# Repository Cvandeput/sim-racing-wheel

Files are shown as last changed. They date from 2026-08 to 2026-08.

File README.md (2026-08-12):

<div align="center">

# Sim Racing Wheel

**Volant de simulation type F1, conçu de zéro : modélisation 3D, PCB custom, firmware Arduino.**

Fusion 360 · PCB 2 couches · Arduino Nano · 18 LEDs RGB · écran OLED · palettes à charnière

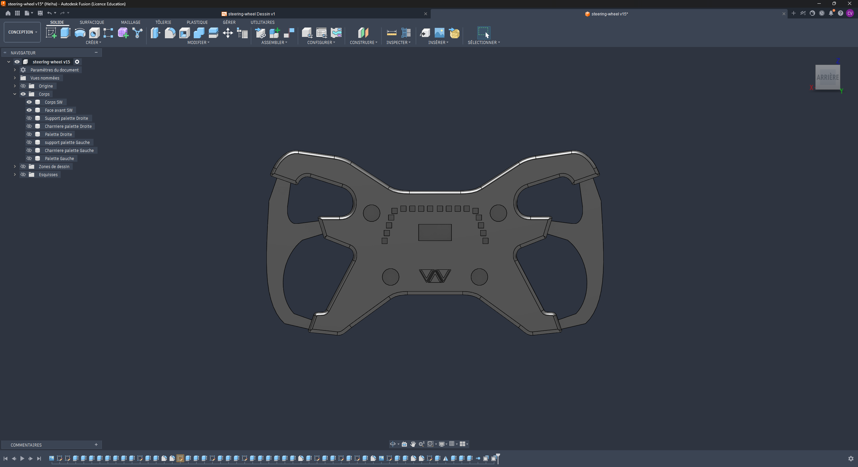
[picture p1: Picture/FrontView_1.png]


</div>

> **🚧 Work in progress** — la mécanique et l'électronique sont finalisées. Le firmware gère l'OLED, les rapports, le chronomètre et le compte-tours ; il reste à le brancher sur une vraie source de télémétrie.

---

## Description

Volant de simulation automobile inspiré des monoplaces de F1, entièrement conçu et fabriqué maison. La coque est modélisée dans Fusion 360 et imprimée en 3D, l'électronique repose sur un PCB deux couches dessiné pour l'occasion, et l'ensemble se connecte en USB-C.

Le volant intègre une barre de 18 LEDs RGB adressables faisant office de compte-tours, un écran OLED central pour la télémétrie, deux encodeurs rotatifs, des boutons poussoirs, et deux palettes de changement de vitesse montées sur charnières.

## Conception 3D

Modélisé sous Fusion 360 en corps séparés : coque principale, face avant, supports de palettes, charnières et palettes gauche/droite.

| Vue de face | Vue trois-quarts |
|:---:|:---:|
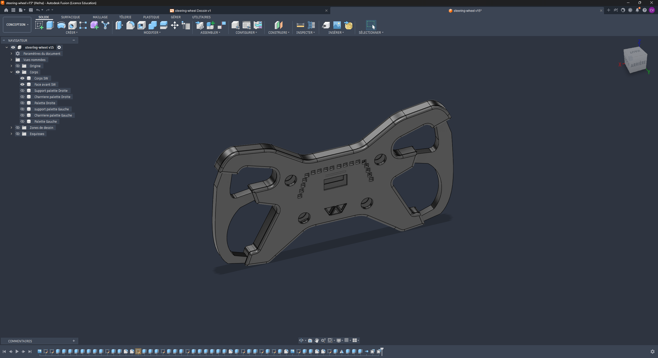
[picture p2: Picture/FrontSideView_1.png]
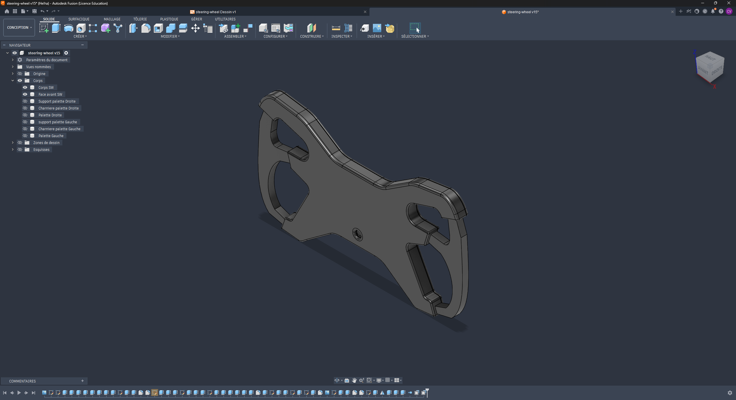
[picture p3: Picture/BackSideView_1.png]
|  |  |

**Face arrière** — nervures de rigidification, logements de vis et passages de câbles vers les palettes.

<div align="center">
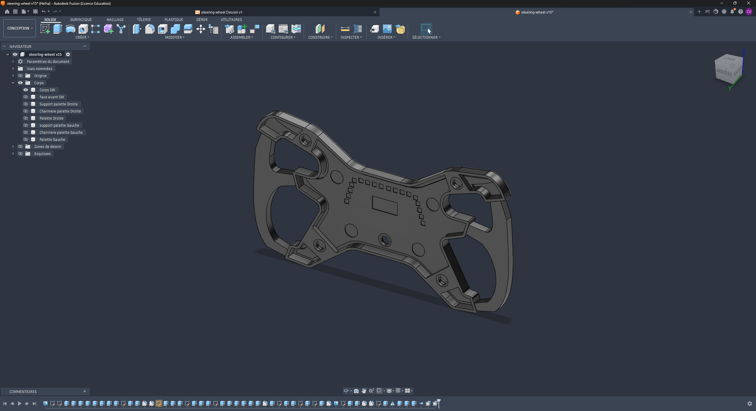
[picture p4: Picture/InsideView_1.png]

</div>

**Dessin technique coté**

<div align="center">
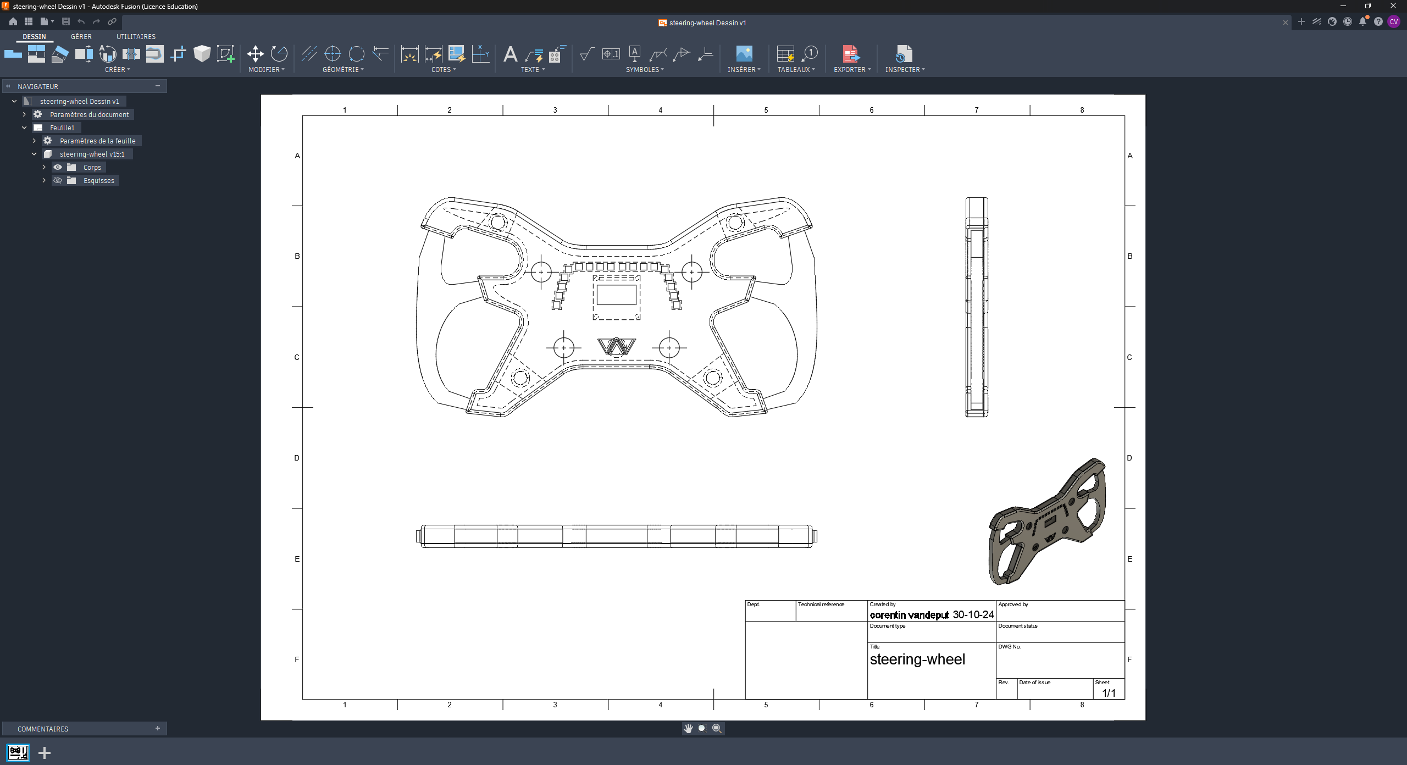
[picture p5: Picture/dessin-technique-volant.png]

</div>

---

## Électronique

PCB deux couches dessiné sous EasyEDA, fichiers Gerber et pick-and-place prêts pour la production.

| Réf. | Qté | Composant | Rôle |
|---|:---:|---|---|
| U1 | 1 | Arduino Nano | Contrôleur, interface USB HID |
| LED1-18 | 18 | WS2812B-V5/W | Barre de compte-tours RGB adressable |
| OLED1 | 1 | HS13L03W2C01 | Affichage télémétrie |
| SW1-2 | 2 | ALPS EC11E09244BS | Encodeurs rotatifs cliquables |
| SWITCH1-2 | 2 | K6-6275D03 | Boutons poussoirs |
| USBC1 | 1 | MC-311D | Connecteur USB-C |
| C1-18 | 18 | 100 nF | Découplage, un par LED |
| R1 | 1 | 470 Ω | Résistance de ligne de données WS2812B |
| R2-5 | 4 | 220 Ω | Limitation de courant |

Nomenclature complète, empreintes et références LCSC dans `PCB/BOM_Board1_PCB1_2024-10-15.xlsx`.

Le découplage à 100 nF par LED et la résistance série de 470 Ω sur la ligne de données suivent les recommandations du fabricant WS2812B — sans elles, une chaîne de 18 LEDs devient instable.

---

## Firmware

Arduino Nano, OLED SSD1306 en I2C, six boutons en `INPUT_PULLUP`, barre de LEDs adressables et potentiomètre simulant le capteur de régime. Le projet est développé et simulable sous Wokwi : [wokwi.com/projects/400891434411566081](https://wokwi.com/projects/400891434411566081).

<div align="center">
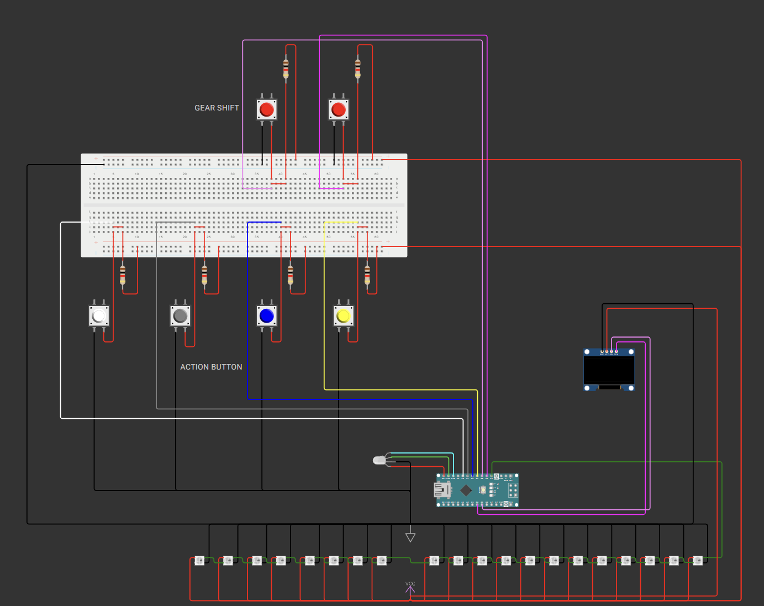
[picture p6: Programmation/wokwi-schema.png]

</div>

### Affectation des broches

| Broche | Signal | Rôle |
|:---:|---|---|
| D2 | `led` (NeoPixel) | Ligne de données de la barre WS2812B |
| D3 | `BP_DWS` | Palette gauche — rétrograder |
| D4 | `BP_UPS` | Palette droite — monter un rapport |
| D5 | `BP_GE` | Affiche le rapport engagé |
| D6 | `BP_CHR_RST` | Remise à zéro du chronomètre |
| D7 | `BP_CHR` | Chronomètre — start / pause / reprise |
| D8 | `BP_RPM` | Affiche le régime moteur |
| A3 | `potentiometre` | Capteur de régime (potentiomètre en simulation) |
| A4 / A5 | `SDA` / `SCL` | Bus I2C de l'OLED (adresse `0x3C`) |

### Fonctionnement

**Rapports** — les palettes incrémentent et décrémentent `Gear_Engaged` de N à 5. L'écran ne se rafraîchit que si le rapport a changé, via `previousGearDisplayed`, pour éviter de redessiner l'OLED à chaque tour de boucle.

**Compte-tours** — la lecture analogique 0-1023 est découpée en vingt paliers qui remplissent progressivement la barre : vert jusqu'à neuf LEDs, puis rouge, puis magenta sur les cinq dernières. C'est la logique classique d'un shift light de F1 : le pilote change de rapport quand la zone magenta s'allume.

**Chronomètre** — machine à trois états (`stop` / `run` / `pause`) avec détection de relâchement du bouton, plus un bouton de reset dédié.

**Écran** — l'affichage courant est mémorisé dans `AFF`, ce qui permet de savoir quelle vue redessiner après un changement d'état.

### Dépendances

`Adafruit GFX`, `Adafruit SSD1306` et `Adafruit NeoPixel` — voir `Programmation/libraries.txt`.

### Points à corriger

- La barre est déclarée à **21 LEDs** dans le firmware alors que le PCB en compte **18**. Les indices 16 à 20 de la zone magenta pointent hors de la chaîne physique.
- L'écran RPM affiche la chaîne littérale `"valeur-RPM"` au lieu de `pot_cap_RPM`.
- Les vingt `if` en cascade du compte-tours sont indépendants et tous évalués à chaque tour ; une boucle avec un seuil calculé ferait la même chose en cinq lignes.
- `MonEcran.setCursor(1000, 1000)` au démarrage place le texte d'initialisation hors de l'écran.
- Les `delay(200)` et `delay(1000)` bloquent la lecture des boutons pendant l'antirebond.

---

## Structure du projet

```
├── 3D/
│   ├── steering-wheel v12.stl / .3mf   # Modèle courant
│   ├── Plan steerign wheel.pdf         # Plan coté
│   └── Previous/                       # Itérations v11 à v13
├── PCB/
│   ├── Gerber_PCB1_2024-10-15.zip      # Fichiers de fabrication
│   ├── BOM_Board1_PCB1_2024-10-15.xlsx # Nomenclature
│   ├── PickAndPlace_PCB1_2024-10-15.*  # Placement composants
│   ├── PCB-steeringWheel.epro          # Projet EasyEDA
│   └── contour-volant.dxf              # Contour du PCB
├── Programmation/
│   ├── sketch.ino                      # Firmware Arduino
│   ├── diagram.json                    # Schéma de câblage Wokwi
│   ├── wokwi-schema.png                # Rendu du schéma
│   ├── libraries.txt                   # Bibliothèques requises
│   ├── logo-binaire.txt                # Bitmap du logo pour l'OLED
│   └── g1177.png                       # Source du logo
└── Picture/                            # Rendus et dessins techniques
```

## Fabrication

**Impression 3D** — imprimer `3D/steering-wheel v12.3mf`. PLA ou PETG, couches de 0.2 mm, remplissage 25 % minimum sur la coque qui encaisse les efforts de direction, supports nécessaires sur les logements de palettes.

**PCB** — envoyer `PCB/Gerber_PCB1_2024-10-15.zip` à un fabricant (JLCPCB, PCBWay). Pour l'assemblage automatisé, joindre le BOM et le fichier pick-and-place, les références LCSC y sont déjà renseignées.

**Firmware** — ouvrir `Programmation/sketch.ino` dans l'IDE Arduino, ou importer `diagram.json` et `sketch.ino` sur Wokwi pour simuler sans matériel.

## Reste à faire

- [x] Publier le firmware Arduino et le schéma Wokwi
- [x] Documenter le mapping des broches
- [x] Piloter la barre WS2812B (compte-tours)
- [ ] Aligner le nombre de LEDs du firmware (21) sur celui du PCB (18)
- [ ] Afficher la vraie valeur de régime sur l'OLED
- [ ] Remplacer la cascade de vingt `if` par une boucle
- [ ] Remplacer les `delay()` par un antirebond non bloquant
- [ ] Remplacer le potentiomètre par une vraie source de télémétrie
- [ ] Photos du volant assemblé
- [ ] Câblage des palettes et choix des switches
- [ ] Support de fixation sur base de force feedback

---

<div align="center">

**Vandeput Corentin** · [devworks.be](https://devworks.be)

</div>

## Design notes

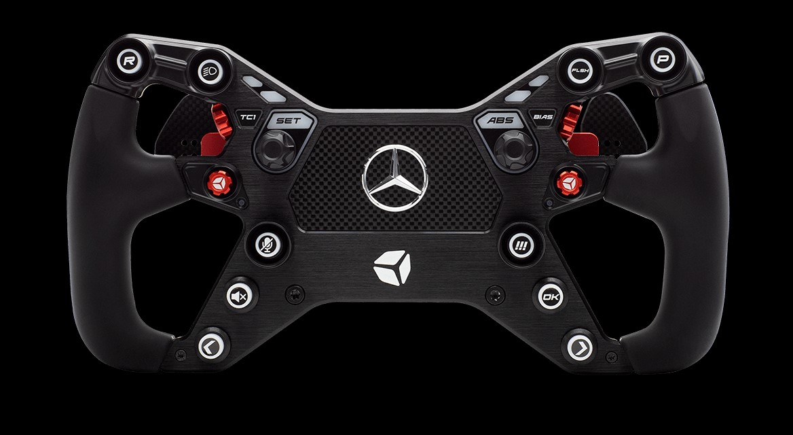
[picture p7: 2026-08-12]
Picture/Capture d’écran 2024-07-02 215142.jpg

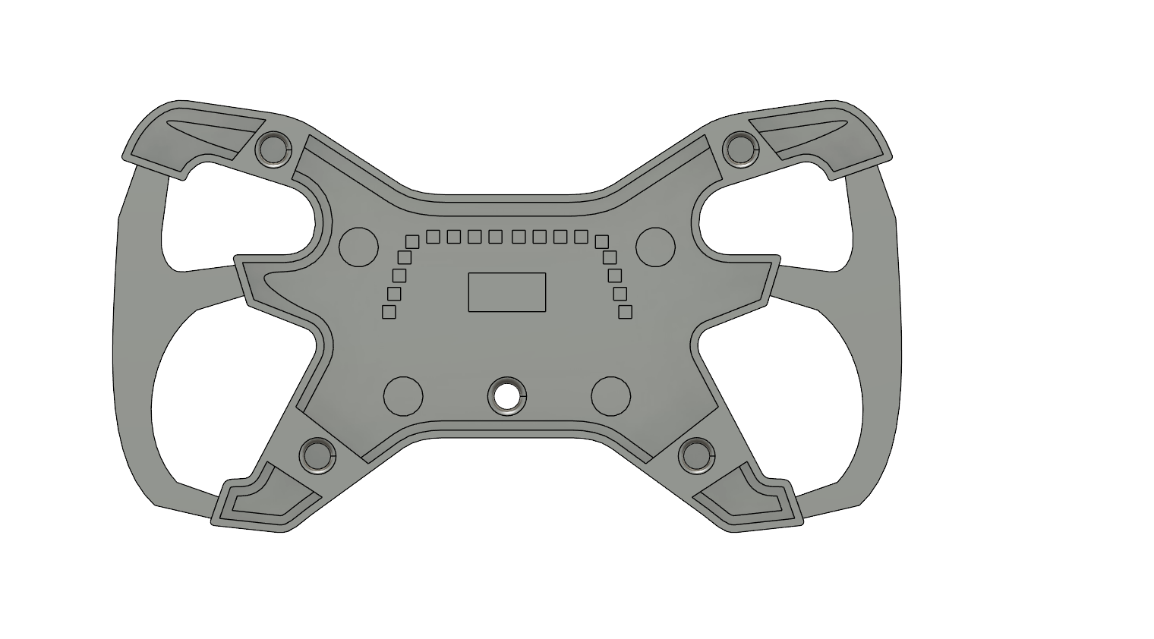
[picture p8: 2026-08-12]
Picture/steering-wheel v10.png

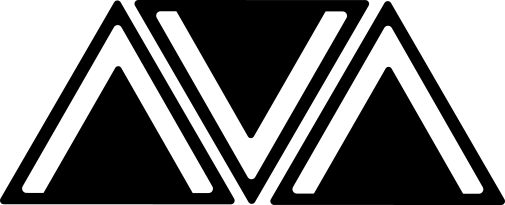
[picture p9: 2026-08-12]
Programmation/g1177.png

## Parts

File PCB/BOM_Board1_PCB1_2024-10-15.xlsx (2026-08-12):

No. | Quantity | Comment | Designator | Footprint | Value | Manufacturer Part | Manufacturer | Supplier Part | Supplier
1 | 18 | 100nF | C1,C2,C3,C4,C5,C6,C7,C8,C9,C10,C11,C12,C13,C14,C15,C16,C17,C18 | C0603 | 100nF | CC0603JRX7R7BB104 | YAGEO(国巨) | C109474 | LCSC
2 | 18 | WS2812B-V5/W | LED1,LED2,LED3,LED4,LED5,LED6,LED7,LED8,LED9,LED10,LED11,LED12,LED13,LED14,LED15,LED16,LED17,LED18 | LED-SMD_4P-L5.0-W5.0-TL-1 |  | WS2812B-V5/W | worldsemi | C2874885 | LCSC
3 | 1 | HS13L03W2C01 | OLED1 | OLED-TH_L35.4-W33.5_HS13L03W2C01 |  | HS13L03W2C01 | HS(汉昇) | C7465997 | LCSC
4 | 1 | 470Ω | R1 | R0603 | 470Ω | CR0603JA0471G | LIZ(丽智电子) | C101353 | LCSC
5 | 4 | 220Ω | R2,R3,R4,R5 | RES-TH_BD2.4-L6.3-P10.30-D0.6 | 220Ω | FMP100JR-52-220R | YAGEO(国巨) | C1742359 | LCSC
6 | 2 | EC11E09244BS | SW1,SW2 | SW-TH_EC11XXXXXXXX |  | EC11E09244BS | ALPSALPINE(阿尔卑斯阿尔派) | C470742 | LCSC
7 | 2 | K6-6275D03 | SWITCH1,SWITCH2 | SW-TH_K6-6275D03 |  | K6-6275D03 | 韩国韩荣 | C693828 | LCSC
8 | 1 | ARDUINO_NANO | U1 | COMM-TH_ARDUINO_NANO |  | ARDUINO_NANO |  | C9900017879 | LCSC
9 | 1 | MC-311D | USBC1 | USB-C-SMD_MC-311D |  | MC-311D | SOFNG(硕方) | C136423 | LCSC

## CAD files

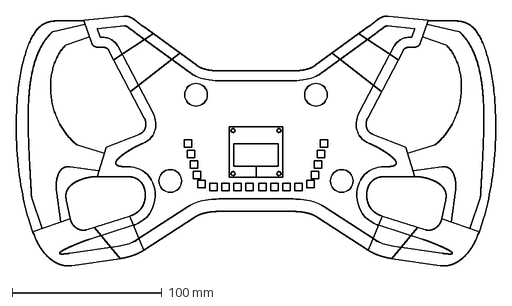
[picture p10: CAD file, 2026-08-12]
PCB/contour-volant.dxf
320.0 x 166.6 mm

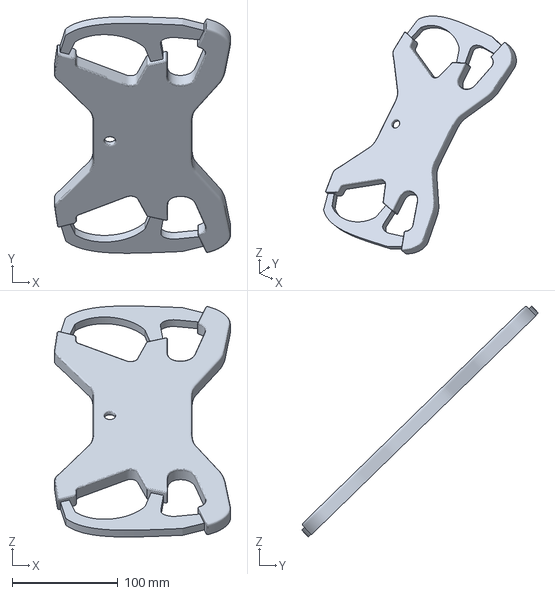
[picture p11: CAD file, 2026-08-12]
3D/steering-wheel v12.3mf
166.9 x 223.9 x 218.6 mm

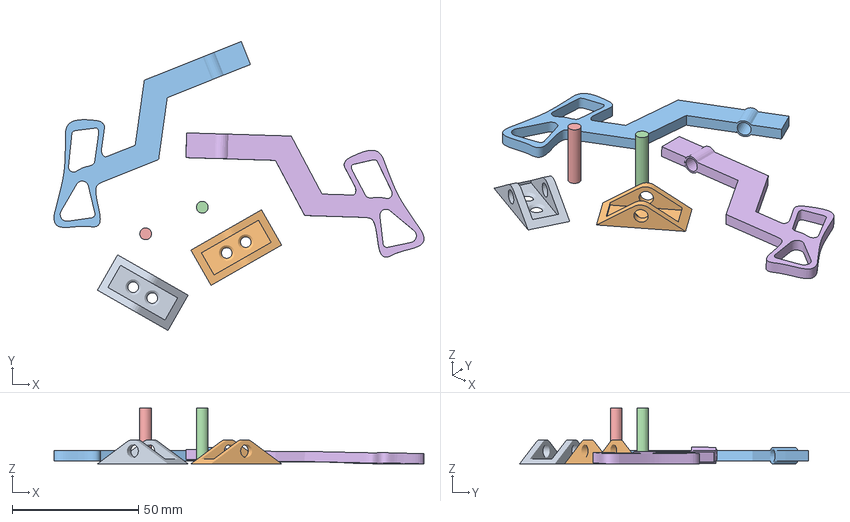
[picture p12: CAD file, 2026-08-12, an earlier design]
3D/Previous/SW-V2 v11.3mf
146.7 x 114.6 x 22.1 mm
SW-V2 v11.stl_1
SW-V2 v11.stl_2
SW-V2 v11.stl_4 x 2
SW-V2 v11.stl_5
SW-V2 v11.stl_6

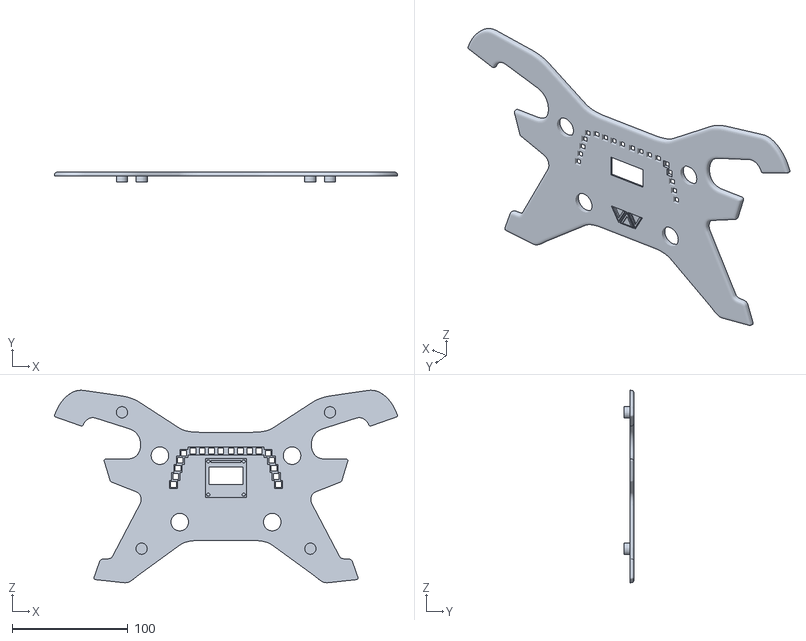
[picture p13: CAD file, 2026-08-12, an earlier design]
3D/steering-wheel v11.stl
296.8 x 8.50 x 166.6

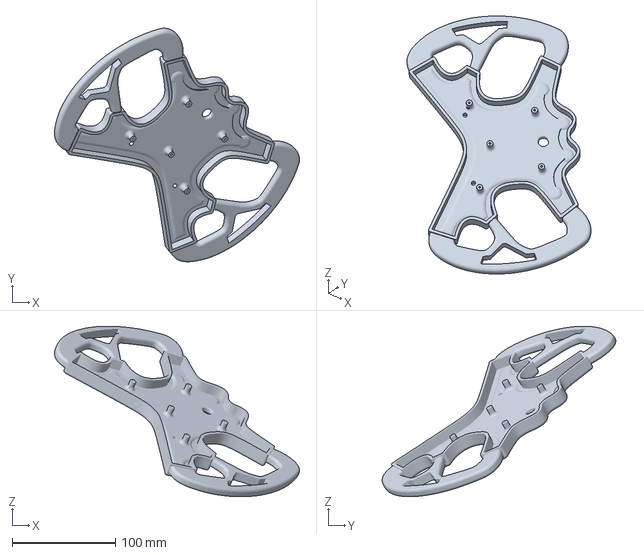
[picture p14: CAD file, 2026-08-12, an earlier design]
3D/Previous/SW-V2 v13.3mf
237.1 x 226.1 x 165.0 mm

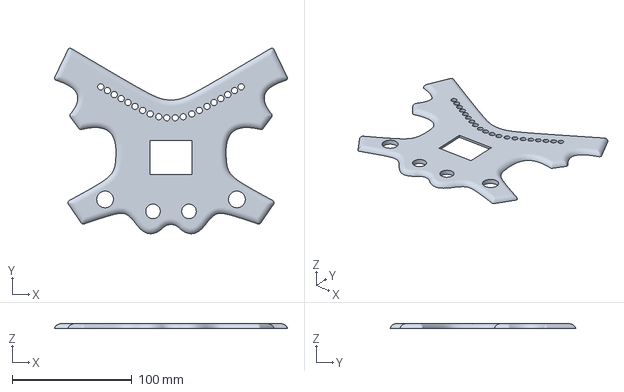
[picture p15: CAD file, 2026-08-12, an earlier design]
3D/Previous/SW-V2 v12.3mf
194.4 x 154.9 x 4.00 mm

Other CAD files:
3D/steering-wheel v12.stl

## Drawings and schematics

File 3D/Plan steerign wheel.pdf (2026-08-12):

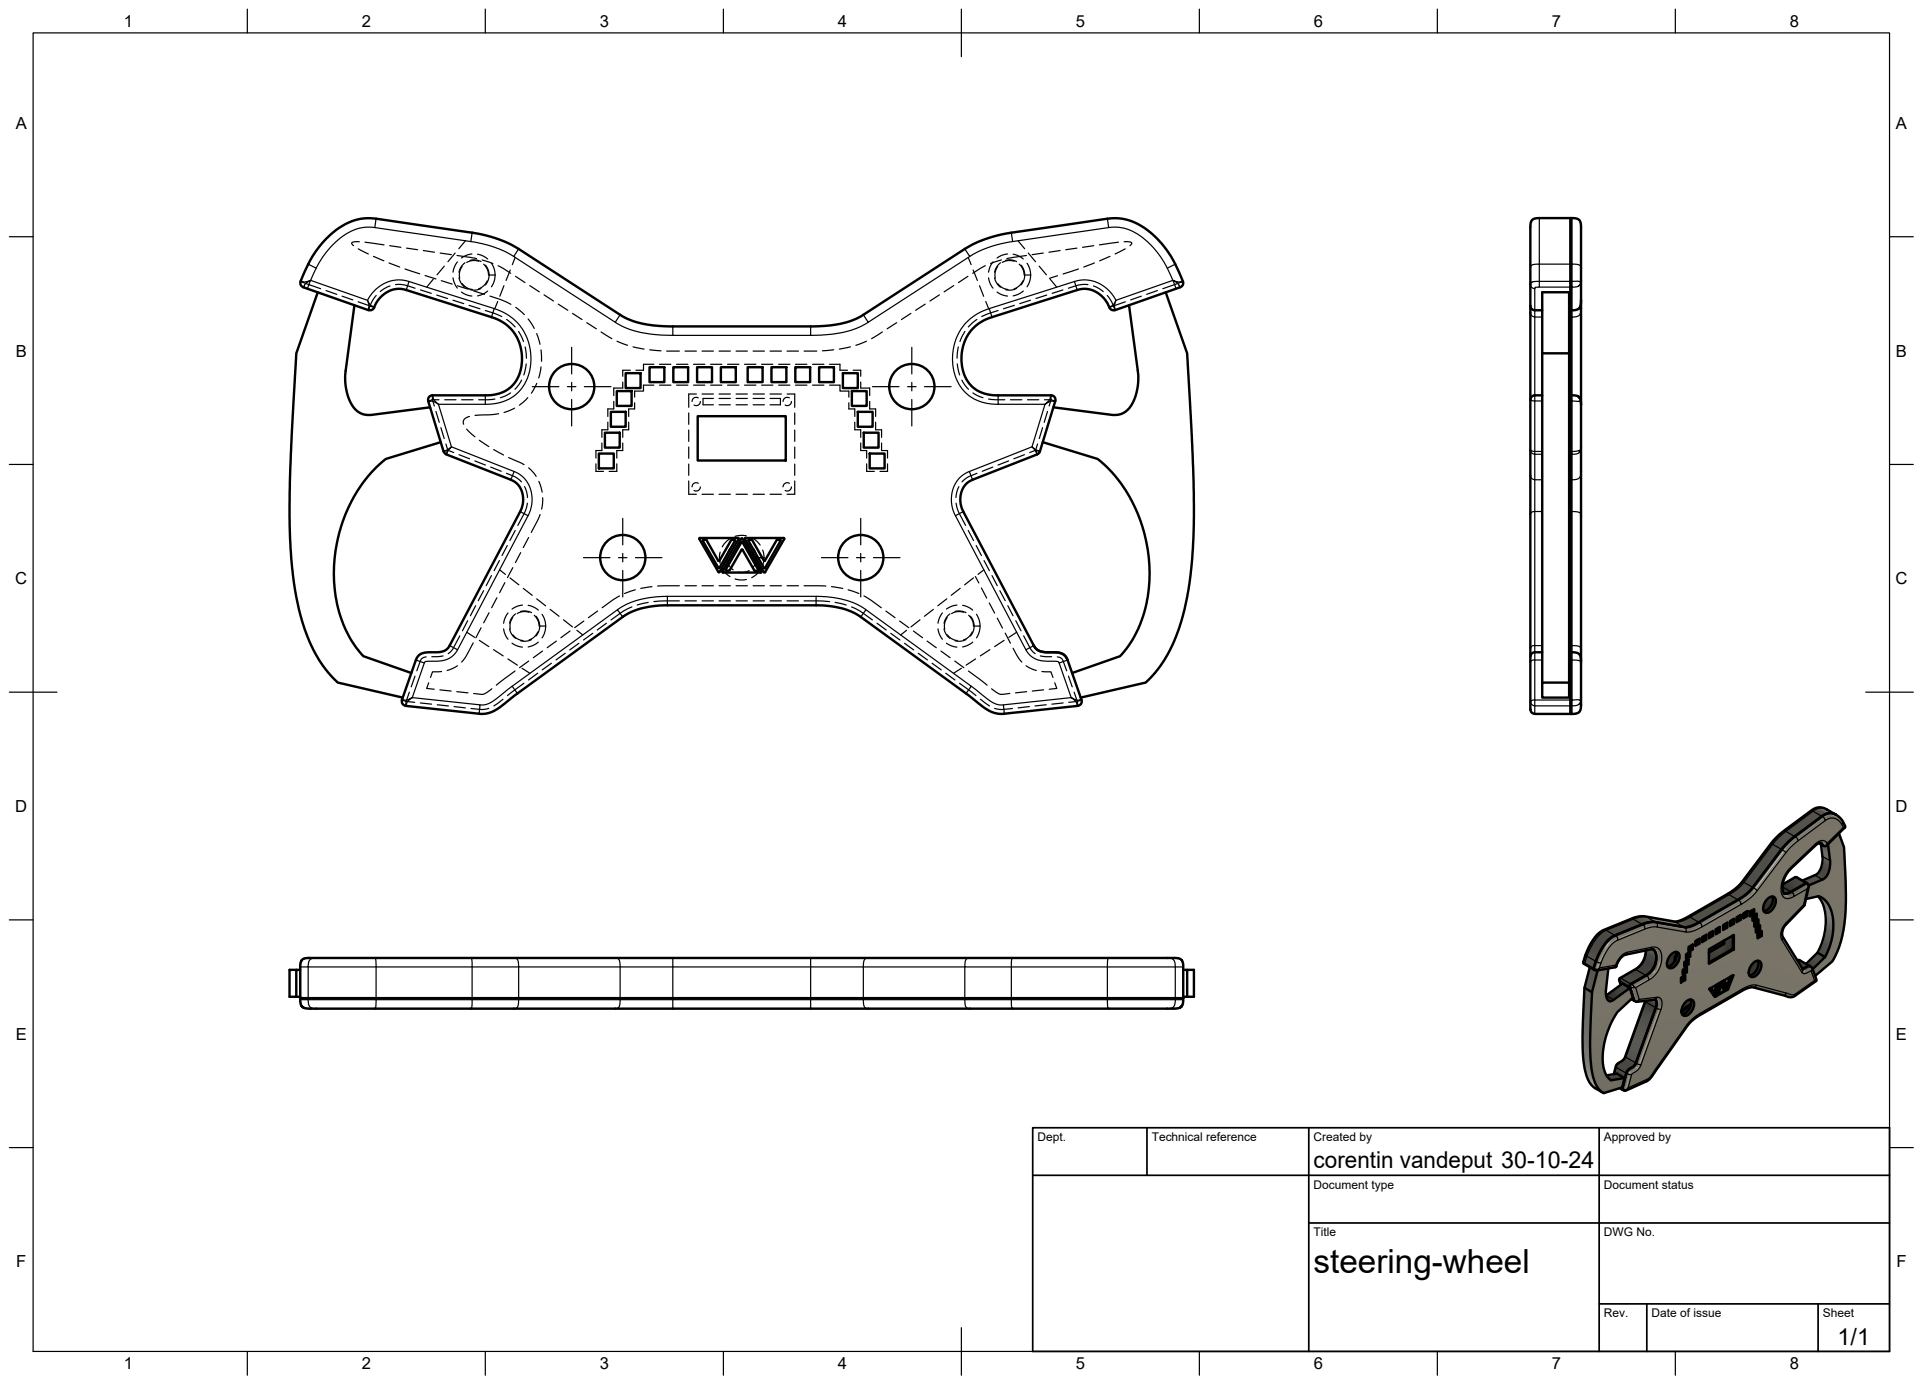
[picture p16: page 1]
Dept.; Technical reference; Created by; Approved by; Document type; Document status; Title; DWG No.; Rev.; Date of issue; Sheet; corentin vandeput

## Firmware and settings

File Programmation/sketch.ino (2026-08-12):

#include <Wire.h>
#include <SPI.h>
#include <Adafruit_GFX.h>
#include <Adafruit_SSD1306.h>
#include <Adafruit_NeoPixel.h>
// define width and height of the ssd1306 
#define SCREEN_WIDTH 128
#define SCREEN_HEIGHT 64
#define OLED_RESET    -1
#define SCREEN_ADDRESS 0x3C

//define width and height of the logo
#define LOGO_HEIGHT 12
#define LOGO_WIDTH 64

//initialisation variables
const char BP_DWS = 3;
const char BP_UPS = 4;
const char BP_GE = 5;
const char BP_CHR_RST = 6;
const char BP_CHR = 7;
const char BP_RPM = 8;

int potentiometre = A3;

//initialisation etat des boutons
char EtatBP_DWS = HIGH;
char EtatBP_GE = HIGH;
char EtatBP_UPS = HIGH;
char EtatBP_CHR_RST = HIGH;
char EtatBP_CHR = HIGH;
char EtatBP_RPM = HIGH;

//initialisation des varaibles comprises dans les actions des boutons
int Gear_Engaged;
int Gear_Prv_Eng;
int RPM = 0;
int PBR_CHR = 0;
int AFF=4;

bool logoDisplayed = false; // initialisation variable pour afficher logo
Adafruit_NeoPixel led(21, 2, NEO_GRB + NEO_KHZ800);

int previousGearDisplayed = -1; // Initialize with an invalid gear value
int pot_cap_RPM;

const int start_pause_pin = 7, resetpin = 6; //initialisation des variables pour chrono
String stopwatch = "stop";
String start_pause = "low";
long start_time = 0;
long seconds = 0;

const unsigned char logo [] PROGMEM = {
0b11111111, 0b11111111, 0b11111111, 0b11111111, 0b11111111, 0b11111111, 0b11111111, 0b11111111,
0b10000000, 0b00000000, 0b00000000, 0b00000000, 0b00000000, 0b00000000, 0b00000000, 0b00000001,
0b10000000, 0b00000000, 0b00000000, 0b00000000, 0b00000000, 0b00000000, 0b00000000, 0b00000001,
0b10000000, 0b00000000, 0b00000000, 0b00000000, 0b00000000, 0b00000000, 0b00000000, 0b00000001,
0b10000000, 0b00000000, 0b00000000, 0b00000000, 0b00000000, 0b00000000, 0b00000000, 0b00000001,
0b10000000, 0b00000000, 0b00000000, 0b00000000, 0b00000000, 0b00000000, 0b00000000, 0b00000001,
0b10000000, 0b00000000, 0b00000000, 0b00000000, 0b00000000, 0b00000000, 0b00000000, 0b00000001,
0b10000000, 0b00000000, 0b00000000, 0b00000000, 0b00000000, 0b00000000, 0b00000000, 0b00000001,
0b10000000, 0b00000000, 0b00000000, 0b00000000, 0b00000000, 0b00000000, 0b00000000, 0b00000001,
0b10000000, 0b00000000, 0b00000000, 0b00000000, 0b00000000, 0b00000000, 0b00000000, 0b00000001,
0b10000000, 0b00000000, 0b00000000, 0b00000000, 0b00000000, 0b00000000, 0b00000000, 0b00000001,
0b11111111, 0b11111111, 0b11111111, 0b11111111, 0b11111111, 0b11111111, 0b11111111, 0b11111111,

};

Adafruit_SSD1306 MonEcran(SCREEN_WIDTH, SCREEN_HEIGHT, &Wire, OLED_RESET);

void setup() {
    Serial.begin(9600);

    if (!MonEcran.begin(SSD1306_SWITCHCAPVCC, 0x3C)) {
        Serial.println(F("SSD1306 allocation failed"));
        for (;;); // Boucle infinie en cas d'échec
    }

    MonEcran.clearDisplay();
    MonEcran.setTextSize(1);
    MonEcran.setTextColor(SSD1306_WHITE);
    MonEcran.setCursor(1000, 1000);
    MonEcran.println(F("Initialisation..."));
    MonEcran.display();
    delay(100);
    MonEcran.clearDisplay();

    // Draw logo
    MonEcran.drawBitmap(32, 23, logo, LOGO_WIDTH, LOGO_HEIGHT, SSD1306_WHITE);
    MonEcran.display();

    pinMode(BP_DWS, INPUT_PULLUP);
    pinMode(BP_UPS, INPUT_PULLUP);
    pinMode(BP_GE, INPUT_PULLUP);
    pinMode(BP_CHR_RST, INPUT_PULLUP);
    pinMode(BP_CHR, INPUT_PULLUP);
    pinMode(BP_RPM, INPUT_PULLUP);

    pinMode(potentiometre, INPUT);

    pinMode(start_pause_pin, INPUT_PULLUP);
    pinMode(resetpin, INPUT_PULLUP);

    led.begin();
    led.show();

    EtatBP_DWS = digitalRead(BP_DWS);
    EtatBP_GE = digitalRead(BP_GE);
    EtatBP_UPS = digitalRead(BP_UPS);
    EtatBP_CHR = digitalRead(BP_CHR);
    EtatBP_RPM = digitalRead(BP_RPM);
    EtatBP_CHR_RST = digitalRead(BP_CHR_RST);
}

void loop() {
  pot_cap_RPM = analogRead(potentiometre); //lecture de l'état du potentiomètre simulant le capteur compte tour
  Serial.println(pot_cap_RPM);
  EtatBP_DWS = digitalRead(BP_DWS);
  EtatBP_GE = digitalRead(BP_GE);
  EtatBP_UPS = digitalRead(BP_UPS);
  EtatBP_CHR = digitalRead(BP_CHR);
  EtatBP_RPM = digitalRead(BP_RPM);
  EtatBP_CHR_RST = digitalRead(BP_CHR_RST);

  if (EtatBP_UPS == LOW && Gear_Engaged != 5 && Gear_Engaged <= 5) {
    Gear_Engaged = Gear_Engaged + 1;
    Gear_Prv_Eng = Gear_Engaged;
    delay(200);
  }
  else if (EtatBP_DWS == LOW && Gear_Engaged > 0) {
    Gear_Engaged = Gear_Engaged - 1;
    Gear_Prv_Eng = Gear_Engaged;
    delay(200);
  }

  // Refresh display if gear changes and display is showing gear information
  if (AFF == 1 && Gear_Engaged != previousGearDisplayed) {
    MonEcran.clearDisplay();
    MonEcran.setCursor(0, 0);
    MonEcran.setTextSize(1);
    MonEcran.print("Gear Engaged: ");
    if (Gear_Engaged != 0) {
      MonEcran.println(Gear_Engaged);
    } 
    else {
      MonEcran.println("N");
    }
    MonEcran.display();
    previousGearDisplayed = Gear_Engaged; // Update previous displayed gear
  }

  if (EtatBP_RPM == LOW) { // RPM
    MonEcran.clearDisplay();
    MonEcran.setCursor(0, 0);
    MonEcran.setTextSize(2);
    MonEcran.print(F("RPM: "));
    MonEcran.println("valeur-RPM");
    MonEcran.display();
    AFF = 2;
    // Afficher la valeur RPM sur le moniteur série pour le débogage
    Serial.print(F("RPM: "));
    Serial.println(RPM);
    delay(100);
  }

  if (EtatBP_GE == LOW) { // Gear engaged
    MonEcran.clearDisplay();
    MonEcran.setCursor(0, 0);
    MonEcran.setTextSize(1);
    MonEcran.print("Gear Engaged: ");
    if (Gear_Engaged != 0) {
      MonEcran.println(Gear_Engaged);
    } 
    else {
      MonEcran.println("N");
    }
    MonEcran.display();
    AFF = 1;
    Serial.print(F("Gear Engaged: "));
    Serial.println(Gear_Engaged);
    previousGearDisplayed = Gear_Engaged; // Update previous displayed gear
    delay(1000);
  }

  if (stopwatch == "run") {
    MonEcran.clearDisplay(); // Efface l'écran avant d'afficher le chronomètre
    MonEcran.setCursor(0, 0);
    MonEcran.print("Chrono");
    MonEcran.setCursor(0, 20);
    seconds = (millis() - start_time) / 1000;
    long centisecond = ((millis() - start_time) % 1000) % 100;
    // Afficher le chrono sur l'afficheur SSD1306
    MonEcran.setCursor(0, 20);   
    MonEcran.print(seconds);
    MonEcran.setCursor(20, 20);   
    MonEcran.print(":");
    MonEcran.setCursor(30, 20);   
    MonEcran.print(centisecond);
    MonEcran.display(); 
    Serial.println(start_time);
    Serial.println(millis());
    AFF = 3;
  }
 
  if (digitalRead(resetpin) == LOW) { // Bouton de réinitialisation en INPUT_PULLUP, donc LOW signifie appuyé
    // Reset stopwatch    
    stopwatch = "stop";
    start_time = 0;
    AFF = 0;
    MonEcran.clearDisplay(); // Efface l'écran avant d'afficher le message "Press Start"
    MonEcran.setCursor(0, 0);
    MonEcran.print("Press");
    MonEcran.setCursor(0, 20);
    MonEcran.print("Start");
    MonEcran.display(); 
  } else if (stopwatch == "stop" && AFF == 0) {
    MonEcran.clearDisplay(); // Efface l'écran avant d'afficher le message "Press Start"
    MonEcran.setCursor(0, 0);
    MonEcran.print("Press");
    MonEcran.setCursor(0, 20);
    MonEcran.print("Start");
    MonEcran.display();
  }

  if (digitalRead(start_pause_pin) == LOW && stopwatch == "stop") { // Bouton de démarrage/pause en INPUT_PULLUP, donc LOW signifie appuyé
    // Start stopwatch
    start_time = millis();
    stopwatch = "run";
    start_pause = "high";
    AFF = 3;
  }
  else if (digitalRead(start_pause_pin) == LOW && stopwatch == "run" && start_pause == "low") {
    // Pause stopwatch
    stopwatch = "pause";
    start_pause = "high";
  }
  else if (digitalRead(start_pause_pin) == LOW && stopwatch == "pause" && start_pause == "low") {
    // Resume stopwatch
    start_time = millis() - (seconds * 1000);
    stopwatch = "run";
    start_pause = "high";
    AFF = 3;
  }
  else if (digitalRead(start_pause_pin) == HIGH) { // Bouton relâché
    start_pause = "low";
  }
  
    //les boucles if qui suivent servent a allumer les leds
  if (pot_cap_RPM >= 0 && pot_cap_RPM < 48){
    led.clear();
    led.setPixelColor(2, led.Color(0, 255, 0));
    led.fill(led.Color(0, 255, 0),2,1);
    led.show();
  }
  if (pot_cap_RPM >= 48 && pot_cap_RPM < 96){
    led.clear();
    led.setPixelColor(3, led.Color(0, 255, 0));
    led.fill(led.Color(0, 255, 0),2,2);
    led.show();
  }
  if (pot_cap_RPM >= 96 && pot_cap_RPM < 144){
    led.clear();
    led.fill(led.Color(0, 255, 0),2,3);
    led.show();
  }
  if (pot_cap_RPM >= 144 && pot_cap_RPM < 192){
    led.clear();
    led.setPixelColor(5, led.Color(0, 255, 0));
    led.fill(led.Color(0, 255, 0),2,4);
    led.show();
  }
  if (pot_cap_RPM >= 192 && pot_cap_RPM < 240){
    led.clear();
    led.fill(led.Color(0, 255, 0),2,5);
    led.show();
  }
  if (pot_cap_RPM >= 240 && pot_cap_RPM < 288){
    led.clear();
    led.fill(led.Color(0, 255, 0),2,6);
    led.show();
  }
  if (pot_cap_RPM >= 288 && pot_cap_RPM < 336){
    led.clear();
    led.fill(led.Color(0, 255, 0),2,7);
    led.show();
  }
  if (pot_cap_RPM >= 336 && pot_cap_RPM < 384){
    led.clear();
    led.fill(led.Color(0, 255, 0),2,8);
    led.show();
  }
  if (pot_cap_RPM >= 384 && pot_cap_RPM < 432){
    led.clear();
    led.fill(led.Color(0, 255, 0),2,9);
    led.show();
  }
  if (pot_cap_RPM >= 432 && pot_cap_RPM < 480){
    led.clear();
    led.fill(led.Color(0, 255, 0),2,9);
    led.fill(led.Color(255, 0, 0),10,1);
    led.show();
  }
  if (pot_cap_RPM >= 480 && pot_cap_RPM < 528){
    led.clear();
    led.fill(led.Color(0, 255, 0),2,9);
    led.fill(led.Color(255, 0, 0),10,2);
    led.show();
  }
  if (pot_cap_RPM >= 528 && pot_cap_RPM < 576){
    led.clear();
    led.fill(led.Color(0, 255, 0),2,9);
    led.fill(led.Color(255, 0, 0),10,3);
    led.show();
  }
  if (pot_cap_RPM >= 576 && pot_cap_RPM < 624){
    led.clear();
    led.fill(led.Color(0, 255, 0),2,9);
    led.fill(led.Color(255, 0, 0),10,4);
    led.show();
  }
  if (pot_cap_RPM >= 624 && pot_cap_RPM < 672){
    led.clear();
    led.fill(led.Color(0, 255, 0),2,9);
    led.fill(led.Color(255, 0, 0),10,5);
    led.show();
  }
  if (pot_cap_RPM >= 672 && pot_cap_RPM < 720){
    led.clear();
    led.fill(led.Color(0, 255, 0),2,9);
    led.fill(led.Color(255, 0, 0),10,6);
    led.show();
  }
  if (pot_cap_RPM >= 720 && pot_cap_RPM < 768){
    led.clear();
    led.fill(led.Color(0, 255, 0),2,9);
    led.fill(led.Color(255, 0, 0),10,6);
    led.fill(led.Color(255, 0, 255),16,1);
    led.show();
  }
  if (pot_cap_RPM >= 768 && pot_cap_RPM < 816){
    led.clear();
    led.fill(led.Color(0, 255, 0),2,9);
    led.fill(led.Color(255, 0, 0),10,6);
    led.fill(led.Color(255, 0, 255),16,2);
    led.show();
  }
  if (pot_cap_RPM >= 816 && pot_cap_RPM < 864){
    led.clear();
    led.fill(led.Color(0, 255, 0),2,9);
    led.fill(led.Color(255, 0, 0),10,6);
    led.fill(led.Color(255, 0, 255),16,3);
    led.show();
  }
  if (pot_cap_RPM >= 864 && pot_cap_RPM < 912){
    led.clear();
    led.fill(led.Color(0, 255, 0),2,9);
    led.fill(led.Color(255, 0, 0),10,6);
    led.fill(led.Color(255, 0, 255),16,3);
    led.show();
  }
  if (pot_cap_RPM >= 912 && pot_cap_RPM < 960){
    led.clear();
    led.fill(led.Color(0, 255, 0),2,9);
    led.fill(led.Color(255, 0, 0),10,6);
    led.fill(led.Color(255, 0, 255),16,4);
    led.show();
  }
  if (pot_cap_RPM >= 960){
    led.clear();
    led.fill(led.Color(0, 255, 0),2,9);
    led.fill(led.Color(255, 0, 0),10,6);
    led.fill(led.Color(255, 0, 255),16,5);
    led.show();
  }
  delay(10);
}

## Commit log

2026-08-12 initial: modeles 3D, PCB, rendus
    [BOM_Board1_PCB1_2024-10-15.xlsx, PickAndPlace_PCB1_2024-10-15.csv, PickAndPlace_PCB1_2024-10-15.xlsx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]
2026-08-12 docs: README avec rendus 3D et nomenclature PCB
2026-08-12 chore: retire les images de reference tierces
